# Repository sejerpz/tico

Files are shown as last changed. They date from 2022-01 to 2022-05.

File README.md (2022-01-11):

# TiCO

Timer per Camera Oscura

Caratteristiche principali:

* Timer per ingranditore lineare o fattoriale
* Provinatore lineare o F-STOP
* Timer per sviluppo a 4 bagni (configurabile)
* Metronomo
* Flusso di lavoro configurabile (es. passaggio automatico da modalità ingranditore a sviluppo)
* Statistiche sul numero di accensioni / tempo totale di funzionamento della lampada ingranditore

TiCO: manuale utente

# Bill of Materials

* 1 arduino nano (es. https://www.amazon.it/gp/product/B0716S43Q2/ref=ppx_yo_dt_b_asin_title_o02_s00?ie=UTF8&psc=1)
* 1 scheda display seriale 7 segmenti x 4, led rossi (**TM1637**) (es. https://www.amazon.it/gp/product/B08KT76Z3G/ref=ppx_yo_dt_b_asin_title_o04_s00?ie=UTF8&psc=1)
* 1 encoder rotativo con bottone (es. https://www.amazon.it/gp/product/B07SV5HHM5/ref=ppx_yo_dt_b_asin_title_o02_s00?ie=UTF8&psc=1)
* 2 pulsanti (es. https://www.amazon.it/gp/product/B0825RCZJS/ref=ppx_yo_dt_b_asin_title_o03_s00?ie=UTF8&psc=1)
* 1 scheda relè (es. https://www.amazon.it/gp/product/B06XHJ2PBJ/ref=ppx_yo_dt_b_asin_title_o07_s01?ie=UTF8&psc=1)
* 1 buzzer
* 1 connettore femmina da 3,5" per switch a pedale (aux switch - opzionale e **non testato**)

# Collegamenti

Schema di collegamento

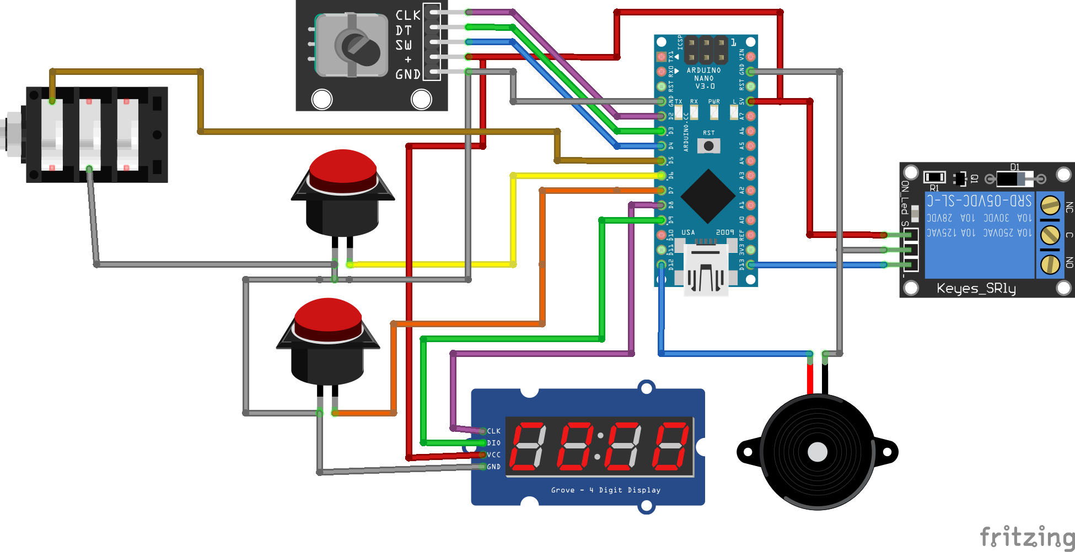
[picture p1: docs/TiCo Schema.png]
alt TiCo Fritzing Schema


E' possibile configurare i pin relativi ai vari componenti nel file TiCO.h

L'encoder prevede 3 pin di collegamento 2 per signal / clock ed 1 per il bottone

    const int encoderPin1 = 2;
    const int encoderPin2 = 3;
    const int button2Pin = 4; // encoder button

Push button Aux

    const int buttonAuxPin = 5; // aux switch

Push button principale

    const int button1Pin = 6; // start / stop

Push button secondario (Focus)

    const int buttonFocusPin = 7; // focus

Display

    const int displayClkPin = 8;
    const int displayDIOPin = 9;

Buzzer

    const int buzzerPin = 12;

Relè

    const int rele1Pin = 13;

# Build

TiCO è sviluppato in c++ (arduino) utilizzando Visual Studio Code e PlatformIO

* Installare Visual Studio Code (https://code.visualstudio.com/)

* Da Visual Studio Code installare l'estensione PlatformIO che installerà anche le estensioni relative allo sviluppo c++ (https://platformio.org/install/ide?install=vscode)

* Aprire la cartella TiCO e fare il build della soluzione `CTRL+ALT+B`

* Se non ci sono errori eseguire l'upload nell'arduino nano `CTRL+ALT+U`

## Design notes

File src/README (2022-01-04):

TiCO - Un timer per camera oscura

BOM

1x Arduino
1x Buzzer
1x Display TM1637 I2C
1x Encoder rotativo con switch
1x Switch
1x Scatola

totale circa 15€

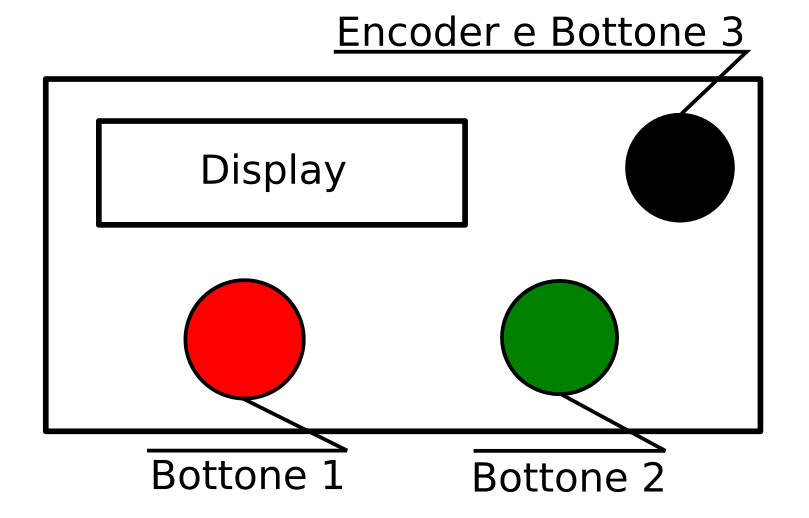
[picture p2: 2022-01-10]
docs/TiCo Front Panel.png

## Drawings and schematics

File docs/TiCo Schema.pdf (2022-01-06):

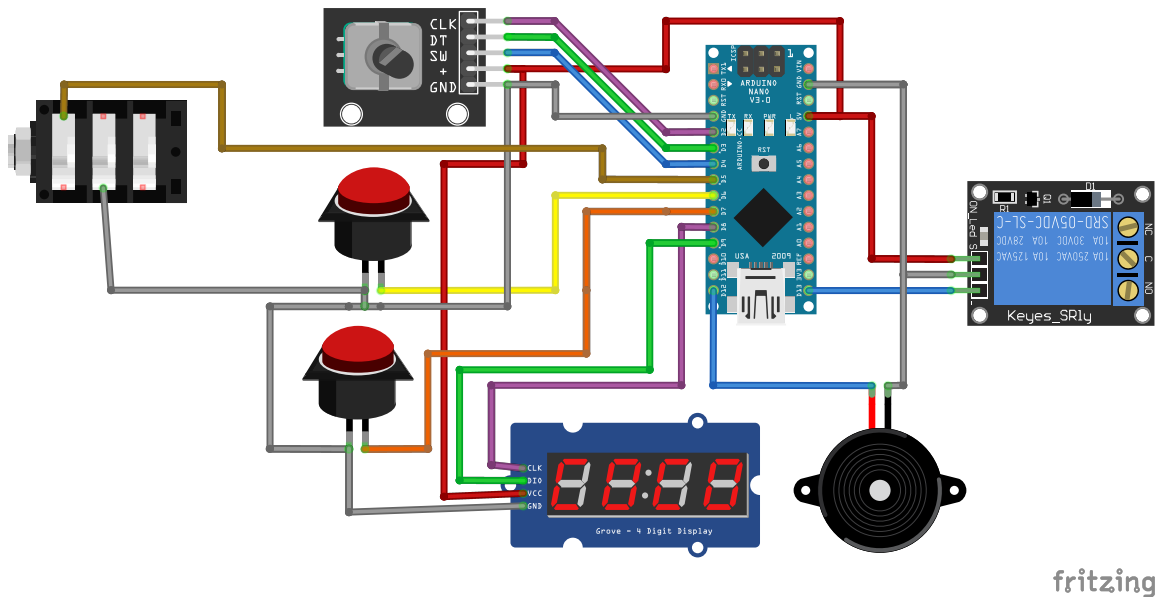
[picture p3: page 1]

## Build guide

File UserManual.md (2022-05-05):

# Manuale TiCO Timer

alt TiCo Front Panel

## Navigazione

||Azione|Descrizione|
|---|---|---|
|Bottone 3|Click|Cambio modalità timer: Provinatore, Ingranditore, Sviluppo, Metronomo|
||Click lungo|Accesso alle impostazioni|

## Segnali acustici

In tutte le modalità lo scorrere di un timer è sempre evidenziato da un segnale acustico ogni 30 sec. ed uno differente ogni minuto.

Per lo sviluppo un segnale acustico avverte che si sta entrando nell'ultimo minuto, poi negli ultimi 30, 15 secondi fino al conto alla rovescia ogni secondo a partire dai 10.

## Modalità **Ingranditore**

In questa modalità il timer è utilizzato per la stampa, attivando un ingranditore collegato all'uscita relé per il tempo di accensione specificato.

E' possibile configurare TiCO in modo che al termine della stampa passi automaticamente nella modalità sviluppo dopo un tempo di pausa specificato o dopo la pressione del **Bottone 1** (vedere i parametri `Dopo SVILUPPO` e `T. PAUSA`)

In modalità F-Stop i tempi saranno impostati in base alla precisione degli step configurati e allo step corrente variabile con l'encoder.
All'attivazione il tempo impostato sarà utilizzato come base per il calcolo del tempo di accensione in relazione allo step corrente.
Questa funzione è utile per effettuare mascherature o bruciature ragionando in stop o frazioni di stop.

||Azione|Descrizione|
|---|---|---|
|Display||**I.** `tempo di accensione ingranditore in sec.`
|Encoder|Rotazione|Aumenta / diminuisce tempo accensione o step corrente in base alla modalità di impostazione tempi configurata|
|Bottone 1|Click|se timer fermo **avvia countdown**|
||Click|se timer avviato in countdown **pause / resume**|
||Click lungo|se timer fermo **cicla edit parametri veloci**|
||Click lungo|se timer avviato in countdown **cancel**|
|Bottone 2|Click|Focus **ON / OFF**|

Parametri veloci disponibili:

|Nome parametro|Descrizione parametro|Valore|Descrizione valore|
|---|---|---|---|
|M|Modalità di impostazione tempi|T|Tempo lineare|
| | |F|Fstop|
|F|Scala F-STOP|F. 1-1 ... F. 1-10|Incremento in stop del tempo di stampa|

## Modalità **Sviluppo Fattoriale**

In questa modalità il timer è utilizzabile per lo sviluppo della carta nel classico processo a 3 bacinelle.

La particolarità dello sviluppo fattoriale consiste in due momenti specifici durante il primo bagno di sviluppo:

1. All'avvio il timer esegue un count up del tempo in attesa che l'immagine inizi a formarsi nella carta `tempo di comparsa`
1. A questo punto l'operatore premendo il **Bottone 1** avvia la seconda fase dello sviluppo il cui tempo è determinato dal `tempo di comparsa` x `il fattore moltiplicativo` impostato.

Ogni catena di sviluppo carta / sviluppo ha un suo fattore moltiplicativo che deve essere determinato sperimentalmente dallo stampatore.

Al termine dello sviluppo il timer passerà ai bagni successivi se abilitati nelle impostazioni (Arresto, Fissaggio 1, Fissaggio 2).

||Azione|Descrizione|
|---|---|---|
|Display||**F.** `fattore moltiplicatore`
|Encoder|Rotazione|Aumenta / diminuisce moltiplicatore|
|Bottone 1|Click|se timer fermo **avvia countup**|
||Click|se timer avviato in countup **avvia countdown**|
||Click|se timer avviato in countdown **pause / resume**|
||Click lungo|se timer avviato in countdown **cancel**|
|Bottone 2|Click|Focus **ON / OFF**|

## Modalità **Sviluppo Lineare**

In questa modalità il timer è utilizzabile per lo sviluppo della carta nel classico processo a 3 bacinelle.

A differenza del metodo **fattoriale** questa modalità prevede un semplice timer count down dove sono impostati i secondi per il bagno di sviluppo.

Al termine il timer passerà ai bagni successivi se abilitati nelle impostazioni (Arresto, Fissaggio 1, Fissaggio 2).

||Azione|Descrizione|
|---|---|---|
|Display||**S.** `tempo di sviluppo in sec.`
|Encoder|Rotazione|Aumenta / diminuisce tempo di sviluppo|
|Bottone 1|Click|se timer fermo **avvia countdown**|
||Click|se timer avviato in countdown **pause / resume**|
||Click lungo|se timer avviato in countdown **cancel**|

## Modalità **Provinatore F-STOP**

Il provinatore F-Stop serve a realizzare il provino scalare e determinare il tempo per ottenere una stampa "di lavoro".

La provinatura di solito avviene tramite l'ausilio di un provinatore provvisto di una finestrella oppure semplicemente facendo scorrere un cartoncino scuro coprendo il foglio che si sta stampando.

Nel primo caso (parametro `Pr. t.Calc` a **Sing.**) il tempo di attivazione dell'ingranditore per ogni esposizione è determinato dal **tempo base** più il tempo relativo al nr di striscia ed allo scostamento in STOP impostato (vedere parametro  `Pr. F-STOP`).

Nel secondo caso (parametro `Pr. t.Calc` a **Diff.**) il tempo e determinato come *delta* fra il tempo di esposizione della striscia precedente ed il **tempo base** più il tempo relativo al nr di striscia ed allo scostamento in STOP impostato (vedere parametro  `Pr. F-STOP`).

Il nr di strisce per ogni provino può essere preimpostato oppure determinato dinamicamente interrompendo la procedura semplicemente con la pressione del **Bottone 1**.

||Azione|Descrizione|
|---|---|---|
|Display||**P.** `tempo base per striscia provino in sec.`
|Encoder|Rotazione|Aumenta / diminuisce tempo base|
|Bottone 1|Click|se timer fermo **avvia provinatura**|
||Click|se timer avviato **arresta la provinatura** (al termine del tempo)|
||Click lungo|se timer fermo cicla fra i parametri di quick edit: **tempo pre-esposizione**, **Provinatore F-STOP**|
|Bottone 2|Click|Focus **ON / OFF**|
|Bottone 2|Click lungo|Attiva modalità **Calcolatrice F-Stop**|

Parametri veloci disponibili:

|Nome parametro|Descrizione parametro|Valore|Descrizione valore|
|---|---|---|---|
|E|Tempo di pre-esposizione in secondi|0|Nessuna pre-esposizione|
| | |1 ... 32|Tempo in secondi|
|F|Provinatore F-STOP|L|Lineare|
|||F. 1-1 ... F. 1-10|Incremento in stop del tempo per striscia provinata|

## Modalità **Calcolatrice F-Stop**

In questa modalità il timer visualizza i tempi di esposizione in base al tipo di provinatura (lineare o f-stop) e alla striscia selezionata tramite l'encoder.

||Azione|Descrizione|
|---|---|---|
|Display||**C.** `visualizza il tempo di esposizione della striscia corrente in sec.`
|Encoder|Rotazione|Incrementa / decrementa la striscia corrente da 0 a ... |
|Bottone 2|Click|Torna alla modalità **Provinatore F-STOP**|
|Bottone 2|Click lungo|Imposta il tempo selezionato e attiva modalità **Ingranditore**|

## Modalità **Metronomo**

In questa modalità il timer funziona come semplice metronomo emettendo da 1 a max 4 beep al secondo.

||Azione|Descrizione|
|---|---|---|
|Display||**b.** `nr beep al sec.`
|Encoder|Rotazione|Aumenta / diminuisce il nr. di beep al secondo da 1...4|
|Bottone 1|Click|se metronomo fermo **avvia metronomo**|
||Click|se metronomo avviato **arresta metronomo**|
|Bottone 2|Click|Focus **ON / OFF**|

# Impostazioni

## Navigazione

||Azione|Descrizione|
|---|---|---|
|Bottone 3|Click|Scorre i parametri delle impostazioni in sequenza|
||Click lungo|Salva ed esce dalla modalità impostazioni|

## Parametri

|Nome parametro|Descrizione parametro|Valore|Descrizione valore|
|---|---|---|---|
|Pr. Nr|Numero di strisce per provino|Man.|Manuale (Bottone 1 per interrompere)|
|||1 ... 20|Nr. di strice per provino (la provinatura si ferma automaticamente)|
|Pr. t.Calc|Modalità di calcolo del tempo per striscia|Sing.|Singola (viene usato un provinatore localizzato con una finestrella)|
|||Diff.|Come differenza dalla striscia precedente (la provinatura viene effettuata nascondendo progressivamente il foglio)|
|Pr. Pausa|Tempo di pausa in sec. fra una striscia e l'altra|OFF|Nessuna pausa|
|||Man.|Avanzamento manuale (Bottone 1 per avanzare)|
|||1 ... 10|Tempo in secondi|
|Dopo STAMPA|Quale modalità attivare al termine della stampa|STOP|Ferma il timer|
|||SVIL.|Entra in modalità SVILUPPO|
|Tipo SVILUPPO|Tipo sviluppo|FATT.|Fattoriale|
|||LIN.|Lineare|
|T. STOP|Tempo bagno di stop|OFF.|Non effettuare il bagno|
|||1 ... 999|Tempo in secondi|
|T. FISSAGGIO|Tempo bagno di fissaggio 1|OFF.|Non effettuare il bagno|
|||1 ... 999|Tempo in secondi|
|T. FISSAGGIO 2|Tempo bagno di fissaggio 2|OFF.|Non effettuare il bagno|
|||1 ... 999|Tempo in secondi|
|Dopo SVILUPPO|Quale modalità attivare al termine dello sviluppo|STOP|Ferma il timer e attiva la modalità iniziale|
|||CRON.|Avvia un cronometro per ulteriori bagni custom|
|T. PAUSA|Tempo di pausa fra un bagno e l'altro|OFF.|Disabilita la pausa|
|||MAN.|Avanzamento manuale (Bottone 1 per avanzare)|
|||1 ... 30|Tempo in secondi|
|BEEP|Avvisi acustici|SI|Avvisi acustici attivati|
|||NO|Nessun beep attivato|
|||PRIN.|Solo i beep principali|
|LUMINOSITA|Livello di luminosità del display|1 ... 7|Da meno a più luminoso|
|STATS|Visualizza alcuni dati statistici|M.|Nr. di minuti di accensione per la lampada|
|||C.|Numero di accensioni della lampada|
|RESET|Reset impostazioni e/o statistiche|NO|Non resettare|
|||PARA.|Resetta tutti le impostazioni ai valori di default|
|||STAT.|Azzera i contatori statistici|
|||TUTT.|Resetta sia i parametri che le statistiche|
||||Il **reset** avviene al salvataggio / uscita dalle impostazioni|

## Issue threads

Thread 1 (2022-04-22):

Pausa: visualizzare un counter intermittente incrementale durante la pausa

sejerpz, 2022-04-22:
Attualmente viene interrotto il countdown e il display lampeggia con il tempo del countdown congelato.

Sarebbe più comodo avere nel display un countup che visualizzi il tempo di pausa

Closed 2022-04-30.

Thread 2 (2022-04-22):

Sviluppo: pressione bottone di focus durante lo sviluppo

sejerpz, 2022-04-22:
Attualmente il bottone di focus non è utilizzato durante le fasi di sviluppo (sviluppo, arresto, fissaggio) potrebbe essere usato per:

* Click: aggiunge 10 secondi alla fase corrente
* Longclick: salta alla fase successiva

Closed 2022-04-30.

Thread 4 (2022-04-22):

Provinatura F-Stop: problema dell'inerzia della lampada

sejerpz, 2022-04-22:
Prevedere una modalità a lampada sempre accesa nella quale l'audio aiuti ad eseguire la provinatura.

Parametri:

se *testStripCountDownTime* è 0 il timer va in modalità "always on"

L'ultimo secondo viene segnalato con un beep lungo possibilmente con volume crescente per indicare che e' necessario spostare velocemente il foglio nella prossima striscia.

Il problema è che in modalità f-stop spesso le prime strice hanno dei tempi piuttosto bassi

Closed 2022-04-30.

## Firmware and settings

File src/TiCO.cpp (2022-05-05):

/*
 *
 * Copyright (C) 2022 Andrea Del Signore
 *
 * This file is part of TiCO.
 * 
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
 * TiCo is distributed in the hope that it will be useful, but WITHOUT ANY WARRANTY; 
 * without even the implied warranty of MERCHANTABILITY or FITNESS FOR A PARTICULAR PURPOSE. 
 * See the GNU General Public License for more details.
 *
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
 * Author:
 *    Andrea Del Signore <sejerpz@gmail.com>
 * 
 */

#include <Arduino.h>
#include <EEPROM.h>

#include "TiCO.h"
#include "TiCOSettings.h"
#include "Watch.h"
#include "Display.h"
#include "Messages.h"
#include "Buzzer.h"

volatile int lastEncoded = 0;
volatile long encoderValue = 0;

int lastMSB = 0;
int lastLSB = 0;

struct Tico {
  TicoSettings settings = TicoSettings();
  TimerStates timerState = TimerStates::Stopped;
  PrintSteps currentPrintStep = PrintSteps::Development;
  bool skipCurrentStep = false;

  TimerModes timerStartMode = TIMER_MODE_DEFAULT;
  unsigned long timerInterval = 0;
  unsigned long timerStartValue = 0;
  unsigned long timerLastChange = 0;
  unsigned long timerPausedStart = 0;
  int timerFStopStep = 0;
  unsigned long releOnStart = 0;

  long timerAdd = 1000;
  byte timerChangeCount = 0;
  int timerChangeDirection = 0;
  
  uint8_t currentPar = 0;
  uint8_t currentStat = 0;

  int testStripCount = 0;
  bool testStripDone = false;
  byte quickEditParameters = 0; // quick edit parameters: 0 = base time, 1 = pre-exp, 2 = f-stops

  byte timerStep = 1;

  long lastencoderValue = 0;

  uint8_t displayBuff[4] = { D_SEG_OFF, D_SEG_OFF, D_SEG_OFF, D_SEG_OFF};
  Buzzer buzzer = Buzzer();

  uint8_t reset = 0;
  bool isMessageInfoVisible = false;

  public:
    

    void startPrint(unsigned long currentMillis) {
      settings.timerMode = TimerModes::EnlargerTimer;
      currentPrintStep = PrintSteps::Printing;
      timerInterval = settings.printTime;
      timerStartValue = currentMillis;
      timerState = TimerStates::RunningDown;
    }

    void startDevel(unsigned long currentMillis) {
      settings.timerMode = TimerModes::Devel;
      currentPrintStep = PrintSteps::Development;

      if (settings.develMode == DevelMode::Linear) {
        timerInterval = settings.develTime;
        timerStartValue = currentMillis;
        timerState = TimerStates::RunningDown;
      } else {
        timerInterval = 0;
        timerState = TimerStates::RunningUp;
      }
    }

    void stop()
    {
      timerState = TimerStates::Stopped;
      buzzer.sound = soundEnd;
    }

    void pause(unsigned long currentMillis) {
      timerPausedStart = currentMillis;
      buzzer.sound = soundPaused;
      if (settings.timerMode == TimerModes::TestStrips && currentPrintStep == PrintSteps::Printing)
        setRele(LOW, currentMillis);
    }

    void resume(unsigned long currentMillis) {
      timerStartValue = timerStartValue + (currentMillis - timerPausedStart);
      timerPausedStart = 0;
      buzzer.sound = soundAck;
      if (settings.timerMode == TimerModes::TestStrips && currentPrintStep == PrintSteps::Printing)
        setRele(HIGH, currentMillis);
    }

    bool isPaused() {
      return timerPausedStart != 0;
    }

    void cancel() {
      timerPausedStart = 0;
      timerState = TimerStates::Stopped;
      buzzer.sound = soundCancel;
    }

    // switch focus on, if action cannot be done due to timer state returns false otherwise returns true
    bool toggleFocus() {
      bool focusToggled = true;

      if (timerState == TimerStates::FocusOn) {
        timerState = TimerStates::Stopped;
        buzzer.sound = soundFocusOff;
      } else {
        if ((settings.timerMode == TimerModes::EnlargerTimer || settings.timerMode == TimerModes::Metronome || settings.timerMode == TimerModes::TestStrips)
            && timerState == TimerStates::Stopped) {
          // focus
          timerState = TimerStates::FocusOn;
        } else {
          // can't toggle focus
          focusToggled = false;
        }
      }

      return focusToggled;
    }
    
    bool setNextStepCountDown(unsigned long currentMillis, PrintSteps nextStep) {
      bool inCountDown = false;

      if ((settings.timerMode == TimerModes::TestStrips && settings.testStripCountDownTime == PARAM_TESTSTRIP_COUNTDOWN_MANUAL)
          || (settings.timerMode == TimerModes::TestStrips && nextStep == PrintSteps::PrintingCountDown && settings.countDownTime == PARAM_TIMER_COUNTDOWN_MANUAL) 
          || (settings.timerMode != TimerModes::TestStrips && settings.countDownTime == PARAM_TIMER_COUNTDOWN_MANUAL)) {
        pause(currentMillis);
      } else if (settings.timerMode == TimerModes::TestStrips) {
        if (nextStep == PrintSteps::TestStripCountDown && settings.testStripCountDownTime > 0) {
          // il primo countdown in modalita' differenziale lo posso tranquillamente saltare
          if (testStripCount != -1 || settings.testStripTimeCalc != PARAM_TESTSTRIP_TIMECALC_DELTA)
          {
            currentPrintStep = nextStep;
            timerInterval = settings.testStripCountDownTime;
            inCountDown = true;
          }
        } else if (nextStep == PrintSteps::PrintingCountDown && settings.countDownTime > 0) {
          currentPrintStep = nextStep;
          timerInterval = settings.countDownTime;
          inCountDown = true;
        }
      } else if (settings.countDownTime > 0) {
        currentPrintStep = nextStep;
        timerInterval = settings.countDownTime;
        inCountDown = true;
      }

      return inCountDown;
    }

    void startTestStrip(unsigned long currentMillis) {
      testStripDone = false;
      currentPrintStep = PrintSteps::Printing;

      if (settings.testStripPreExpos > 0) {
        testStripCount = -1;
        timerInterval = settings.testStripPreExpos;
      } else {
        testStripCount = 0;
        if (settings.testStripFStop > 0) {
          // fstop
          if (settings.testStripTimeCalc == PARAM_TESTSTRIP_TIMECALC_SINGLE)
            timerInterval = calculateFStopTime(settings.printFStopBaseTime, settings.printFStop, testStripCount);
          else
            timerInterval = calculateCurrentStripDeltaTime();
        } else {
          // lineare
          timerInterval = settings.testStripBaseTime;
        }
      }
      timerStartValue = currentMillis;
      quickEditParameters = 0; // reset to default parameter
      timerState = TimerStates::RunningDown;
    }

    void nextTestStrip(unsigned long currentMillis) {
      currentPrintStep = PrintSteps::Printing;
      testStripCount++;
      if (settings.testStripFStop > 0) {
          // fstop
          if (settings.testStripTimeCalc == PARAM_TESTSTRIP_TIMECALC_SINGLE)
            timerInterval = calculateFStopTime(settings.printFStopBaseTime, settings.printFStop, testStripCount);
          else
            timerInterval = calculateCurrentStripDeltaTime();
      } else {
        // lineare
        timerInterval = settings.testStripBaseTime;
      }
      timerStartValue = currentMillis;
      if (settings.testStripStripCount > 0 && testStripCount == settings.testStripStripCount - 1) {
        endTestStrip(currentMillis);
      }
    }

    void endTestStrip(unsigned long currentMillis) {
      testStripDone = true;
      buzzer.sound = soundAck;
    }

    void startCounter(unsigned long currentMillis) {
      timerState = TimerStates::RunningUp;
      currentPrintStep = PrintSteps::Counter;
      timerStartValue = currentMillis;
      timerInterval = 0;
    }

    // da https://www.analogica.it/post204604.html#p204604
    // base time × 2 ^ (step * fstopStep)
    // se ci fossero problemi di spazio sostuire pow con tabella lookup precalcolata
    // baseTime: tempo base
    // fStopScale: scala in fstop (es. 1/10 di stop)
    // currentFStop: fstop corrente per il quale eseguire il calcolo
    unsigned long calculateFStopTime(int baseTime, int fStopScale, int currentFStop) {
      unsigned long time = ((((double)baseTime / 1000.0) * pow(2, (1.0 / fStopScale) * currentFStop)) + 0.005) * 1000;

      return time;
    }

    unsigned long calculateCurrentStripDeltaTime() {
      // previous step time
      unsigned long prevStepTime = 0;
      
      if (testStripCount > 0)
        prevStepTime = calculateFStopTime(settings.testStripBaseTime, settings.testStripFStop, testStripCount - 1);
   
      return calculateFStopTime(settings.testStripBaseTime, settings.testStripFStop, testStripCount) - prevStepTime;
    }

    // reset settings to default values
    void resetSettings() {
      settings.timerMode = TimerModes::EnlargerTimer;
      settings.printTime = PARAM_TIMER_ENLARGER_DEFAULT;
      settings.printMode = PARAM_TIMER_ENLARGER_MODE_DEFAULT;
      settings.printFStop = PARAM_TIMER_ENLARGER_FSTOP_DEFAULT;
      settings.printFStopBaseTime = 0;
      settings.develMode = DevelMode::Factorial;
      settings.develTime = PARAM_TIMER_DEVEL_DEFAULT;
      settings.stopTime = PARAM_TIMER_STOP_DEFAULT;
      settings.fix1Time = PARAM_TIMER_FIX1_DEFAULT;
      settings.fix2Time = PARAM_TIMER_FIX2_DEFAULT;
      settings.countDownTime = PARAM_TIMER_COUNTDOWN_DEFAULT;
      settings.develFactor = PARAM_TIMER_FACT_DEFAULT;
      settings.brightness = PARAM_BRIGHTNESS_DEFAULT;
      settings.sounds = SoundMode::All;
      settings.afterPrintGoTo = PARAM_AFTER_PRINT_DEFAULT;
      settings.afterDevelGoTo = PARAM_AFTER_DEVEL_DEFAULT;
      settings.testStripBaseTime = PARAM_TIMER_TESTSTRIP_DEFAULT;
      settings.testStripStripCount = PARAM_TESTSTRIP_STRIPCOUNT_DEFAULT;
      settings.testStripCountDownTime = PARAM_TESTSTRIP_COUNTDOWN_DEFAULT;
      settings.testStripFStop = PARAM_TESTSTRIP_FSTOP_DEFAULT;
      settings.testStripTimeCalc = PARAM_TESTSTRIP_TIMECALC_DEFAULT;
      settings.testStripPreExpos = PARAM_TESTSTRIP_PREEXPOS_DEFAULT;
      settings.magic = TICO_MAGIC_SIGNATURE;
    }

    void resetStatistics() {
      settings.onCount = 0;
      settings.onTime = 0;
    }
    // validate each settings with max / min values
    void validateSettings() {
      if ((int)settings.timerMode < 0 || (int)settings.timerMode > MAX_TIMER_MODES)
        settings.timerMode = TIMER_MODE_DEFAULT;

      if ((int)settings.develMode < 0 || (int)settings.develMode > DevelMode::Factorial)
          settings.develMode = TIMER_DEVEL_MODE_DEFAULT;

      settings.printTime = settings.printTime >= PARAM_TIMER_ENLARGER_MIN && settings.printTime <= PARAM_TIMER_ENLARGER_MAX ? settings.printTime : PARAM_TIMER_ENLARGER_DEFAULT;
      settings.printFStopBaseTime = settings.printFStopBaseTime >= PARAM_TIMER_ENLARGER_MIN && settings.printFStopBaseTime <= PARAM_TIMER_ENLARGER_MAX ? settings.printFStopBaseTime : PARAM_TIMER_ENLARGER_DEFAULT;
      switch (settings.printMode)
      {
        case PrintMode::Time:
          break;
        case PrintMode::FStop:
          settings.printTime = 0;
          timerFStopStep = 0;
          break;
        default:
          settings.printMode = PARAM_TIMER_ENLARGER_MODE_DEFAULT;
          break;
      }
      settings.printFStop = settings.printFStop >= PARAM_TIMER_ENLARGER_FSTOP_MIN && settings.printFStop <= PARAM_TIMER_ENLARGER_FSTOP_MAX ? settings.printFStop : PARAM_TIMER_ENLARGER_FSTOP_DEFAULT;
      settings.develTime = settings.develTime >= PARAM_TIMER_DEVEL_MIN && settings.develTime <= PARAM_TIMER_DEVEL_MAX ? settings.develTime : PARAM_TIMER_DEVEL_DEFAULT;
      settings.stopTime = settings.stopTime >= PARAM_TIMER_STOP_MIN && settings.stopTime <= PARAM_TIMER_STOP_MAX ? settings.stopTime : PARAM_TIMER_STOP_DEFAULT;
      settings.fix1Time = settings.fix1Time >= PARAM_TIMER_FIX_MIN && settings.fix1Time <= PARAM_TIMER_FIX_MAX ? settings.fix1Time : PARAM_TIMER_FIX1_DEFAULT;
      settings.fix2Time = settings.fix2Time >= PARAM_TIMER_FIX_MIN && settings.fix2Time <= PARAM_TIMER_FIX_MAX ? settings.fix2Time : PARAM_TIMER_FIX2_DEFAULT;
      settings.countDownTime = settings.countDownTime >= PARAM_TIMER_COUNTDOWN_MIN && settings.countDownTime <= PARAM_TIMER_COUNTDOWN_MAX ? settings.countDownTime : PARAM_TIMER_COUNTDOWN_DEFAULT;
      settings.develFactor = settings.develFactor >= PARAM_TIMER_FACT_MIN && settings.develFactor <= PARAM_TIMER_FACT_MAX ? settings.develFactor : PARAM_TIMER_FACT_DEFAULT;
      settings.bps = settings.bps >= PARAM_BPM_MIN && settings.bps <= PARAM_BPM_MAX ? settings.bps : PARAM_BPM_DEFAULT;
      settings.brightness = settings.brightness >= PARAM_BRIGHTNESS_MIN && settings.brightness <= PARAM_BRIGHTNESS_MAX ? settings.brightness : PARAM_BRIGHTNESS_DEFAULT;
      settings.sounds = (int)settings.sounds < SoundModeCount ? settings.sounds : SoundMode::All;
      settings.testStripBaseTime = settings.testStripBaseTime >= PARAM_TIMER_TESTSTRIP_MIN && settings.testStripBaseTime <= PARAM_TIMER_TESTSTRIP_MAX ? settings.testStripBaseTime : PARAM_TIMER_TESTSTRIP_DEFAULT;
      settings.testStripStripCount = settings.testStripStripCount >= PARAM_TESTSTRIP_STRIPCOUNT_MIN && settings.testStripStripCount <= PARAM_TESTSTRIP_STRIPCOUNT_MAX ? settings.testStripStripCount : PARAM_TESTSTRIP_STRIPCOUNT_DEFAULT;
      settings.testStripCountDownTime = settings.testStripCountDownTime >= PARAM_TESTSTRIP_COUNTDOWN_MIN && settings.testStripCountDownTime <= PARAM_TESTSTRIP_COUNTDOWN_MAX ? settings.testStripCountDownTime : PARAM_TESTSTRIP_COUNTDOWN_DEFAULT;
      settings.testStripFStop = settings.testStripFStop >= PARAM_TESTSTRIP_FSTOP_MIN && settings.testStripFStop <= PARAM_TESTSTRIP_FSTOP_MAX ? settings.testStripFStop : PARAM_TESTSTRIP_FSTOP_DEFAULT;
      settings.testStripPreExpos = settings.testStripPreExpos >= PARAM_TESTSTRIP_PREEXPOS_MIN && settings.testStripPreExpos <= PARAM_TESTSTRIP_PREEXPOS_MAX ? settings.testStripPreExpos : PARAM_TESTSTRIP_PREEXPOS_DEFAULT;
      settings.testStripTimeCalc = settings.testStripTimeCalc >= PARAM_TESTSTRIP_TIMECALC_MIN && settings.testStripTimeCalc <= PARAM_TESTSTRIP_TIMECALC_MAX ? settings.testStripTimeCalc : PARAM_TESTSTRIP_TIMECALC_DEFAULT;
      switch (settings.afterPrintGoTo)
      {
        case TimerModes::EnlargerTimer:
        case TimerModes::Devel:
          break;
        default:
          settings.afterPrintGoTo = PARAM_AFTER_PRINT_DEFAULT;
          break;
      }
      switch (settings.afterDevelGoTo)
      {
        case TimerModes::Devel:
        case TimerModes::Metronome:
          break;
        default:
          settings.afterDevelGoTo = PARAM_AFTER_DEVEL_DEFAULT;
          break;
      }
    }

    void setRele(uint8_t val, unsigned long millis)
    {
      digitalWrite(rele1Pin, val);
      if (val == HIGH && releOnStart == 0) {
        releOnStart = millis;
      } else if (val == LOW && releOnStart != 0) {
        settings.onCount++;
        settings.onTime += millis - releOnStart;
        releOnStart = 0;
      } 
    }
} tico;

void onButton1Clicked (Watch::Event *evt);
void onButton2Clicked (Watch::Event *evt);
void onButtonFocusClicked (Watch::Event *evt);
void onTimerDisplayElapsed (Watch::Event *evt);
void onTimerSoundElapsed (Watch::Event *evt);
void onTimerStatusChanged (Watch::Event *evt);
void onDisplayChanged (Watch::Event *evt);
void onSettingsChanged (Watch::Event *evt);
void onBuzzerChanged (Watch::Event *evt);
void onEncoderChanged (Watch::Event *evt);
void onCurrentParChanged (Watch::Event *evt);
void onCurrentPrintStepChanged (Watch::Event *evt);
void displayCurrentMode ();
void displayCurrentParDes ();
void displayParValue (uint8_t par);
void displayCurrentParValue ();
void clearDisplay ();

Watch::Button button1 = Watch::Button(button1Pin, onButton1Clicked, 50,  1500, LOW);
Watch::Button button2 = Watch::Button(button2Pin, onButton2Clicked);
Watch::Button button3 = Watch::Button(buttonFocusPin, onButtonFocusClicked, 50,  1500, LOW);
Watch::Timer timerDisplay = Watch::Timer(100, onTimerDisplayElapsed, false);
Watch::Timer timerSound = Watch::Timer(50, onTimerSoundElapsed);
Watch::Memory timerStatusMemory = Watch::Memory(&tico.timerState, sizeof(TimerStates), onTimerStatusChanged);
Watch::Memory displayMemory = Watch::Memory(tico.displayBuff, 4, onDisplayChanged);
Watch::Memory settingsMemory = Watch::Memory(&tico.settings, sizeof(TicoSettings), onSettingsChanged);
Watch::Memory buzzerMemory = Watch::Memory(&tico.buzzer, sizeof(int *), onBuzzerChanged);
Watch::Memory encoderMemory = Watch::Memory((void *)&encoderValue, sizeof(long), onEncoderChanged);
Watch::Memory currentParMemory = Watch::Memory((void *)&tico.currentPar, sizeof(uint8_t), onCurrentParChanged);
Watch::Memory currentPrintStepMemory = Watch::Memory((void *)&tico.currentPrintStep, sizeof(PrintSteps), onCurrentPrintStepChanged);
Watch::Event *ctx[] = { &button1, &button2, &button3, 
                        &settingsMemory, &displayMemory, 
                        &buzzerMemory,  &timerStatusMemory, 
                        &encoderMemory, &currentParMemory, &currentPrintStepMemory,
                        &timerDisplay, &timerSound, 
                        NULL };

Display *display;

int encodeTestStripSettings(uint8_t *msg) {
  int len;

  // informazioni sulla modalita' e sugli stop
  if (tico.settings.testStripFStop == 0) {
    msg[0] = D_SEG_L;
    msg[1] = D_SEG_I;
    msg[2] = D_SEG_N | D_SEG_POINT;
    len = 3;
  } else {
    msg[0] = D_SEG_F;
    msg[1] = D_SEG_MINUS;
    msg[2] = D_SEG_S | D_SEG_POINT;
    if (tico.settings.testStripFStop == 1) {
      msg[4] = D_SEG_1;
      len = 5;
    } else {
      msg[4] = D_SEG_1;
      msg[5] = D_SEG_MINUS;
      if (tico.settings.testStripFStop == 10) {
        msg[6] = D_SEG_1;
        msg[7] = D_SEG_0;
        len = 8;
      } else {
        msg[6] = display->encodeDigit(tico.settings.testStripFStop);
        len = 7;
      }
    }
  }
  
  return len;
}

void onDisplayInfoMessageDone() {
  tico.isMessageInfoVisible = false;
  displayCurrentMode();
}

void displayTimerModeInfoMessage() {
  uint8_t *msg = NULL;
  uint8_t len = 0;

  switch (tico.settings.timerMode)
  {
    case TimerModes::EnlargerTimer:
      msg = msg_INFO_TIMERMODE_EnlargerTimer;
      len = sizeof(msg_INFO_TIMERMODE_EnlargerTimer);
      break;
    case TimerModes::Devel:
      msg = msg_INFO_TIMERMODE_Devel;
      len = sizeof(msg_INFO_TIMERMODE_Devel);
      if (tico.settings.develMode == DevelMode::Linear) {
        msg[4] = D_SEG_L;
        msg[5] = D_SEG_I;
        msg[6] = D_SEG_N | D_SEG_POINT;
      } else {
        msg[4] = D_SEG_F;
        msg[5] = D_SEG_A;
        msg[6] = D_SEG_T | D_SEG_POINT;
      }
      break;
    case TimerModes::FactorialCalculator:
      msg = msg_INFO_TIMERMODE_FactorialCalculator;
      len =  encodeTestStripSettings(msg + 5) + 5;
      break;
    case TimerModes::Metronome:
      msg = msg_INFO_TIMERMODE_Metronome;
      len = sizeof(msg_INFO_TIMERMODE_Metronome);
      break;
    case TimerModes::TestStrips:
      msg = msg_INFO_TIMERMODE_TestStrips;
      len = encodeTestStripSettings(msg + 3) + 3;
      break;
  }

  if (msg != NULL) {
    tico.isMessageInfoVisible = true;
    clearDisplay();
    display->showMessage(msg, len, onDisplayInfoMessageDone, 1);
  }
}

void displayMessage(uint8_t *msg) {
  for(unsigned int i=0;i < sizeof(tico.displayBuff); i++) {
    tico.displayBuff[i] = msg == NULL ? D_SEG_OFF : msg[i];
  }
}

void displayInteger(int number, uint8_t pointChar = 4) {
  byte digit = number / 1000;
  tico.displayBuff[0] = digit == 0 ? D_SEG_OFF : display->encodeDigit (digit);
  digit = (number / 100) % 10;
  tico.displayBuff[1] = digit == 0 && tico.displayBuff[0] == D_SEG_OFF ? D_SEG_OFF : display->encodeDigit (digit);
  digit = (number / 10) % 10;
  tico.displayBuff[2] = pointChar >= 4 && digit == 0 && tico.displayBuff[1] == D_SEG_OFF ? D_SEG_OFF : display->encodeDigit (digit);
  digit = (number) % 10;
  tico.displayBuff[3] = display->encodeDigit (digit);

  if (pointChar < 4) {
    tico.displayBuff[pointChar] = tico.displayBuff[pointChar] | D_SEG_POINT;
  }
}

// display a time value or the word OFF if time is zero
void displayTimeOrOff(unsigned long time, int precision = 1000) {
  if (time == 0) {
    displayMessage(msg_OFF);
  } else {
    displayInteger(time / precision);
  }
}

void clearDisplay() {
  displayMessage(NULL);
}

void onTimerStatusChanged (Watch::Event *evt) {
  switch (tico.timerState)
  {
    case TimerStates::RunningDown:
    case TimerStates::RunningUp:
      timerDisplay.change(100, evt->currentMillis, true);
      tico.buzzer.sound = soundStart;
      if (tico.currentPrintStep == PrintSteps::Printing) {
        tico.setRele(HIGH, evt->currentMillis);
      }
      break;
    default:
      timerDisplay.change(100, evt->currentMillis, false);

      if (tico.timerState == TimerStates::Settings) {
          displayCurrentParDes();
          tico.setRele(LOW, evt->currentMillis);
      } else if (tico.timerState == TimerStates::Stopped) {
          tico.settings.timerMode = tico.timerStartMode;
          displayCurrentMode();
          tico.setRele(LOW, evt->currentMillis);
      } else if (tico.timerState == TimerStates::FocusOn) {
          tico.buzzer.sound = soundAck;
          tico.setRele(HIGH, evt->currentMillis);
          displayMessage(msg_FOCUSON);
      }
  }
}

void onCurrentPrintStepChanged (Watch::Event *evt) {
  switch (tico.currentPrintStep)
  {
    case PrintSteps::Printing:
      tico.buzzer.sound = soundStart;
      tico.setRele(HIGH, evt->currentMillis);
      break;
    case PrintSteps::TestStripCountDown:
    case PrintSteps::PrintingCountDown:
    case PrintSteps::Fix1CountDown:
    case PrintSteps::Fix2CountDown:
    case PrintSteps::StopCountDown:
      tico.buzzer.sound = soundStartCountDown;
      tico.setRele(LOW, evt->currentMillis);
      break;
    default:
      tico.buzzer.sound = soundStart;
      tico.setRele(LOW, evt->currentMillis);
      break;
  }
}

void onCurrentParChanged (Watch::Event *evt) {
  displayCurrentParDes();
}
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
void loop(){
  unsigned long currentMillis = millis();

  Watch::loop(ctx, currentMillis);

  updateStatus(currentMillis);

  display->loop(currentMillis);
}

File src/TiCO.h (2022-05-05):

/*
 *
 * Copyright (C) 2022 Andrea Del Signore
 *
 * This file is part of TiCO.
 * 
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
 * TiCo is distributed in the hope that it will be useful, but WITHOUT ANY WARRANTY; 
 * without even the implied warranty of MERCHANTABILITY or FITNESS FOR A PARTICULAR PURPOSE. 
 * See the GNU General Public License for more details.
 *
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
 * Author:
 *    Andrea Del Signore <sejerpz@gmail.com>
 * 
 */

#ifndef TICO_H
#define TICO_H

const int encoderPin1 = 2;
const int encoderPin2 = 3;
const int button1Pin = 6; // start / stop
const int button2Pin = 4; // encoder button
const int buttonFocusPin = 7; // focus
const int buttonAuxPin = 5; // aux switch
const int buzzerPin = 12;
const int displayClkPin = 8; //pins definitions for TM1637 and can be changed to other ports
const int displayDIOPin = 9;
const int rele1Pin = 13;

#define PARAM_TIMER_DEVEL_MIN 1000
#define PARAM_TIMER_DEVEL_DEFAULT 120000
#define PARAM_TIMER_DEVEL_MAX 999000
#define PARAM_TIMER_ENLARGER_MIN 100
#define PARAM_TIMER_ENLARGER_DEFAULT 30000
#define PARAM_TIMER_ENLARGER_MAX 999000
#define PARAM_TIMER_ENLARGER_MODE_MIN 0
#define PARAM_TIMER_ENLARGER_MODE_DEFAULT (PrintMode::Time)
#define PARAM_TIMER_ENLARGER_MODE_MAX 1
#define PARAM_TIMER_ENLARGER_FSTOP_MIN 1
#define PARAM_TIMER_ENLARGER_FSTOP_DEFAULT 3
#define PARAM_TIMER_ENLARGER_FSTOP_MAX 10
#define PARAM_TIMER_TESTSTRIP_MIN 1000
#define PARAM_TIMER_TESTSTRIP_DEFAULT 2000
#define PARAM_TIMER_TESTSTRIP_MAX 99000
#define PARAM_TIMER_STOP_MIN 0
#define PARAM_TIMER_STOP_DEFAULT 10000
#define PARAM_TIMER_STOP_MAX 60000
#define PARAM_TIMER_FIX_MIN 0
#define PARAM_TIMER_FIX1_DEFAULT 120000
#define PARAM_TIMER_FIX2_DEFAULT 0
#define PARAM_TIMER_FIX_MAX 999000
#define PARAM_TIMER_COUNTDOWN_MIN 0
#define PARAM_TIMER_COUNTDOWN_DEFAULT 10000
#define PARAM_TIMER_COUNTDOWN_MANUAL 31000
#define PARAM_TIMER_COUNTDOWN_MAX 31000

#define PARAM_TESTSTRIP_STRIPCOUNT_MIN 0
#define PARAM_TESTSTRIP_STRIPCOUNT_DEFAULT 0
#define PARAM_TESTSTRIP_STRIPCOUNT_MAX 20
#define PARAM_TESTSTRIP_COUNTDOWN_MIN 0
#define PARAM_TESTSTRIP_COUNTDOWN_DEFAULT 3000
#define PARAM_TESTSTRIP_COUNTDOWN_MANUAL 11000
#define PARAM_TESTSTRIP_COUNTDOWN_MAX 11000
#define PARAM_TESTSTRIP_FSTOP_MIN 0
#define PARAM_TESTSTRIP_FSTOP_DEFAULT 3
#define PARAM_TESTSTRIP_FSTOP_MAX 10
#define PARAM_TESTSTRIP_PREEXPOS_MIN 0
#define PARAM_TESTSTRIP_PREEXPOS_DEFAULT 0
#define PARAM_TESTSTRIP_PREEXPOS_MAX 60000
#define PARAM_TESTSTRIP_TIMECALC_MIN 0
#define PARAM_TESTSTRIP_TIMECALC_DEFAULT 0
#define PARAM_TESTSTRIP_TIMECALC_SINGLE 0
#define PARAM_TESTSTRIP_TIMECALC_DELTA 1
#define PARAM_TESTSTRIP_TIMECALC_MAX 1

#define PARAM_BRIGHTNESS_MIN 1
#define PARAM_BRIGHTNESS_DEFAULT 1
#define PARAM_BRIGHTNESS_MAX 7

#define PARAM_TIMER_FACT_MIN 1.0f
#define PARAM_TIMER_FACT_DEFAULT 8.0f
#define PARAM_TIMER_FACT_MAX 25.0f
#define PARAM_BPM_MIN 1
#define PARAM_BPM_DEFAULT 1
#define PARAM_BPM_MAX 4


#define PARAM_VOICE_MIN 0
#define PARAM_VOICE_DEFAULT (VoiceControlMode::Disabled)
#define PARAM_VOICE_MAX 3

#define PARAM_AFTER_PRINT_DEFAULT (TimerModes::EnlargerTimer)
#define PARAM_AFTER_DEVEL_DEFAULT (TimerModes::Devel)

// setting parameters
#define PARAM_TESTSTRIP_STRIPCOUNT 0
#define PARAM_TESTSTRIP_MODE 1
#define PARAM_TESTSTRIP_CDOWN 2
#define PARAM_AFTER_PRINT 3
#define PARAM_DEVEL_MODE 4
#define PARAM_TSTOP 5
#define PARAM_TFIX1 6
#define PARAM_TFIX2 7
#define PARAM_AFTER_DEVEL 8
#define PARAM_CDOWN 9
#define PARAM_SOUND 10
#define PARAM_BRIGHTNESS 11
#define PARAM_STATISTICS 12
#define PARAM_RESET 13
#define PARAM_COUNT 14

// quick edit parameters
#define PARAM_TESTSTRIP_PRETIME 100
#define PARAM_TESTSTRIP_FSTOP 101
#define PARAM_TIMER_ENLARGER_MODE 102
#define PARAM_TIMER_ENLARGER_FSTOP 103

#define TIMER_MODE_DEFAULT (TimerModes::TestStrips)
#define TIMER_DEVEL_MODE_DEFAULT (DevelMode::Factorial)

#define TICO_MAGIC_SIGNATURE 0x50

#define FIX_THRESHOLD 30000         
#define ENCODER_ACCEL_THRESHOLD 16
#define ENCODER_MAX_TIMER_STEP 5000
#define LONG_CLICK_TIME 3000
#define ENCODER_TICKS 4 // Tick for each encoder step
#define EE_ADDR_TIMER_SETTINGS 0x00
#define MAX_TIMER_MODES 3 // l'utima modalita' (FactorialCalculator) non e' selezionabile

enum TimerModes {
  TestStrips,
  EnlargerTimer,
  Devel,
  Metronome,
  FactorialCalculator
};



enum TimerStates {
  Stopped,
  RunningDown,
  RunningUp,
  Settings,
  FocusOn
};

enum PrintSteps {
  Printing,
  PrintingCountDown,
  TestStripCountDown,
  Development,
  StopCountDown,
  Stop,
  Fix1CountDown,
  Fix1,
  Fix2CountDown,
  Fix2,
  Counter
};

enum SoundMode {
  Quiet,
  StartStop,
  All
};

enum VoiceControlMode {
  Disabled,
  StartTraining,
  Enabled,
};

enum PrintMode {
  Time, // encoder: increment / decrement time in seconds or fractions
  FStop   // encoder: increment / decrement time in f-stop fractions
};

enum DevelMode {
  Linear,
  Factorial
};

const int SoundModeCount = SoundMode::All + 1;

#endif

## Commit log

2022-01-04 Added minimal sw/hw information to make a TiCO timer
2022-01-04 deleted unused code and fix documentation
    [TiCO.cpp, TiCO.h]
2022-01-05 First schema draw
    [TiCo Schema.fzz]
2022-01-06 Schema & documentation update
    [TiCo Schema.fzz]
2022-01-10 Added some explanations to TiCO timer modes
2022-04-22 Issue #3 - Focus: eliminare l'audio o renderlo meno evidente.
    [TiCO.cpp]
2022-04-22 Issue #1 - Pausa: visualizzare un counter intermittente incrementale
    [TiCO.cpp]
2022-04-22 Issue #5 - Sviluppo: aggiungere un beep relativo ad ogni minuto passato dall'inizio dello sviluppo
    [TiCO.cpp]
2022-04-26 Issue #6 - Provinatura scalare: pausa non necessaria per la prima striscia
    [TiCO.cpp]
2022-04-30 Fix countup in pausa
    [TiCO.cpp]
2022-04-30 Moved FactorialCalculator activation to focus button long click
2022-04-30 In factorial calculator mode button focus long press switch to enlarger timer with current print interval
2022-04-30 Issue #4 - Provinatura F-Stop: problema dell'inerzia della lampada
    [TiCO.cpp]
2022-04-30 Button focus click add 10sec to current development step
2022-05-05 Fix timer sounds
2022-05-05 Add FStop mode to enlarger timer
2022-05-05 Fix quick print mode activation from TestStrip mode
    [TiCO.cpp]
2022-05-05 Fix pre-time parameter display
    [TiCO.cpp]

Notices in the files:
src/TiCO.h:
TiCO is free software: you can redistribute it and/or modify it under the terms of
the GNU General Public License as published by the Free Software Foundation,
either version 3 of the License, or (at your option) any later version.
